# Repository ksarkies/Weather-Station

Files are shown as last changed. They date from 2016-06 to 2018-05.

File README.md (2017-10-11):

Weather Station
---------------

This project aims to produce a weather station consisting of a weatherproofed
processing unit for control and data capture from sensors. This would be
remotely mounted in a suitable location with the sensors and will communicate
with a base station over a serial cable or wirelessly.

The remote unit is ARM Cortex CM3 based and is powered either from the serial
link (if present) and/or from a solar panel with battery backup.

The base station collects and stores data and permit configuration of the
system via a user interface. It consists of a Linux based PC or microcomputer
unit.

Some of the sensors initially are taken from a defunct low cost commercial
weather station. Later they may be replaced with scientific grade sensors.

The sensors to be used are:

1. Temperature and humidity (indoor and outdoor),
2. Wind Speed,
3. Wind Direction,
4. Rainfall,
5. Barometric Pressure,
6. Solar Radiance.

The solar panel provided for power is also used to measure the incident
solar radiance. This is a measure specific to the panel type and is intended
only for providing records of incident radiance for use in design of solar
power generators having similar panel types.

**The battery must be present when the panel is connected**, as high voltages
from the panel can damage the components, and also because the panel is
disconnected from the power circuits during solar irradiance measurements,
which will result in the circuit losing all power.

(c) K. Sarkies 16/08/2017

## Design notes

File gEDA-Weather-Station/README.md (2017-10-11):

Weather Station Interface Board: gEDA Version
---------------------------------------------

This PCB version will not be updated. The Kicad version will be used instead.

This board provides the interface between the processor and the solar panel.
The panel is used to measure solar irradiation by measuring the (almost) short
circuit current which has a quite linear relationship with the incident
illuminance.

The panel is also used to charge the battery that powers the station. This
charging is done between measurements and is independent of them. A measurement
is taken by activating a digital output from the processor, which turns on a
MOSFET to the current measurement circuit. This effectively shorts out the
panel. At the same time the battery charger circuit is disabled to avoid any
possible interference with the measurements.

A small FM640A 6V 4AH Lead Acid battery is used for powering the system. 
The circuit manages battery charging by limiting the battery voltage through
a linear regulator with an output voltage controlled from the processor. The
battery voltage and charging current is passed to the processor for management
battery health.

A 3.3V power is supplied for the processor, and 5V power for the operational
amplifier. The LM324 has a 3.5V output limit with this supply voltage. The
LM324 also draws only about 0.7mA from the battery. The processor can be placed
into sleep mode between measurements to reduce power drain.

Design Notes
------------

The LM324 has been given a supply voltage VDD of 5V. The outputs can reach
VDD-1.5V which limits them to 3.5V; within the range of the processor input
voltage limits.

The variable voltage regulator based on the 7805 has a voltage setting 
resistor. The 7805 has a quiescent current of a few milliamps which flows
through this resistor and sets a minimum voltage. After some experimentation
it was found that a 470 ohm resistor would set a minimum voltage of 0.8V and a
maximum of 3.3V. The LM324 can source as much as 60mA which is sufficient to
maintain this maximum voltage. This provides an output voltage range between
5.5V and 8.0V. As long as it is more than 7.5V it will provide a valuable
natural limit on the battery charging voltage. Using a D/A converter to drive
this voltage will allow accurate setting of voltages according to battery
temperature. An option for testing purposes allows a fixed voltage provided by
jumper lead as any selected processor may not have a D/A converter. Once the
charging current falls below a given threshold the processor must terminate
charging.

A Schottky diode prevents the battery discharging back through the circuit when
measurements are being taken (as both MOSFETs may be on simultaneously for a
brief period when they are switched).

(c) K. Sarkies 10/06/2016

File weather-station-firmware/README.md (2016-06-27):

Weather Station Firmware
--------------------------

The firmware for the remote weather station unit provides interfacing to
the sensors in its vicinity. Communication with a base station or external PC
is done over a serial cable. It is possible that a wireless interface could be
added in the future.

The firmware powers down the unit to sleep, and wakes on interrupt from a
sensor, or at regular preset times to take measurements with non-interrupting
sensors and to make connection with any attached base station.

The firmware also controls charging of the backup battery from the solar
panel. This is done by monitoring the battery voltage during bulk charge and
applying a limit when it reaches absorption phase. Charging is then stopped
when the current falls below the 0.02C level (C being the battery capacity).

The Makefile currently includes the load script for the STM32F103RET6 used on
the ET Stamp module. Change this to STM32F103RBT6 if the ET-STM32F103
development board is used.

The sensors are allocated to the following GPIO ports:
* PA0 Rainfall Gauge using EXTI interrupt.
* PA1 Temperature and Humidity from DTH22.
* PA2 Wind speed using EXTI interrupt.
* PA3 Wind direction using EXTI interrupt.
* PA4 Solar radiance current using ADC12-IN4.
* Air pressure. This is I2C and needs I2C1_SCL on PB6 and I2C1_SDA on PB7.

For battery charging the following are needed:
* PA5 from a D/A converter DAC_OUT2 to control the battery charging voltage.
* PA6 to measure the battery voltage on ADC12-IN6.
* PA7 to measure the battery current on ADC12-IN7.
* PB4 to switch the panel to the solar radiance current measurement circuit.
* PB5 to disable battery charging.

This allocation allows ports to be used directly without remap on the STM32F103.

(c) K. Sarkies 07/05/2016

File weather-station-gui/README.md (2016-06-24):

Weather Station User Interface
------------------------------

This GUI is intended to run on an attached PC or base station. Its purpose
is to provide a display of current weather conditions, collect stored data and
allow control and configuration of the remote unit.

The GUI is taken substantially from the Battery Management System project with
reuse of the recording module to allow recorded data to be downloaded via the
serial interface. A configuration interface is also available.

(c) K. Sarkies 12/06/2016

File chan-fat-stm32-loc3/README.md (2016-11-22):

This is an adaptation of ChaN's FatFS FAT filesystem library based on v0.12.

Common files are ff.c, ff.h, ffconf.h, integer.h, diskio.h. These should be
updated when a new version of ChaN FAT library is released. Ensure that any
changes to ffconf.h are reflected in the new version.

The remaining files adapt the library to the hardware being used and to
libopencm3. Some changes to these may be necessary if the ChaN FAT API
changes.

Currently the makefile calls on sd_spi_loc3_stm32.c

(c) K. Sarkies 22/11/2016

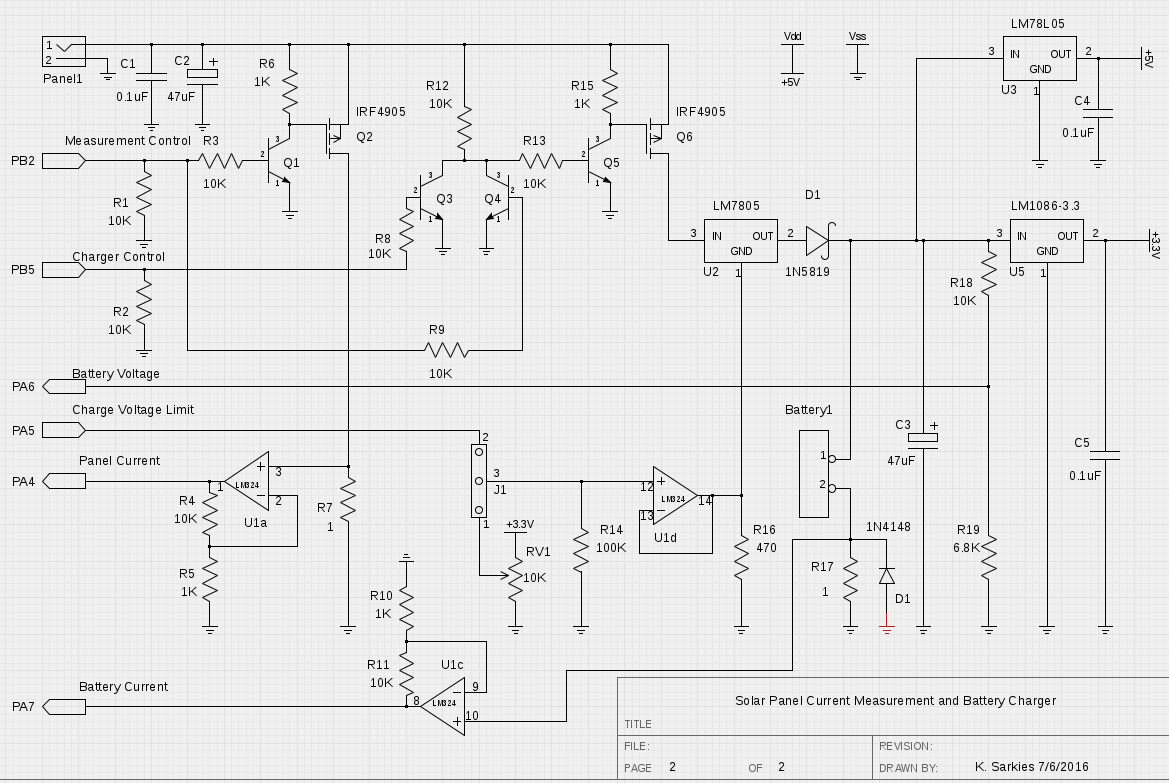
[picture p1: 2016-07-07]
gEDA-Weather-Station/weather-station-power.png

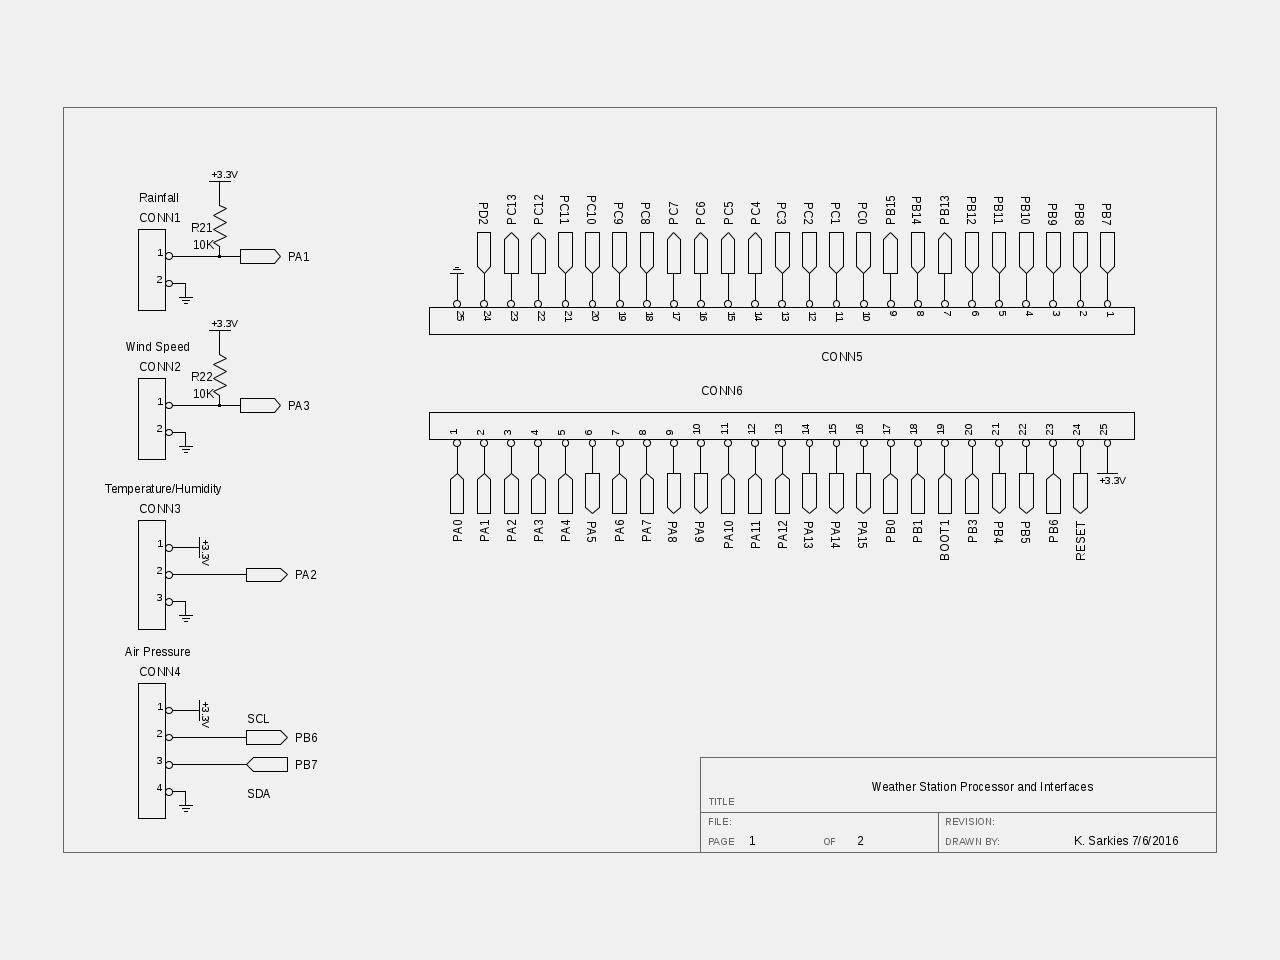
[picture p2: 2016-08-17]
gEDA-Weather-Station/weather-station-processor.png

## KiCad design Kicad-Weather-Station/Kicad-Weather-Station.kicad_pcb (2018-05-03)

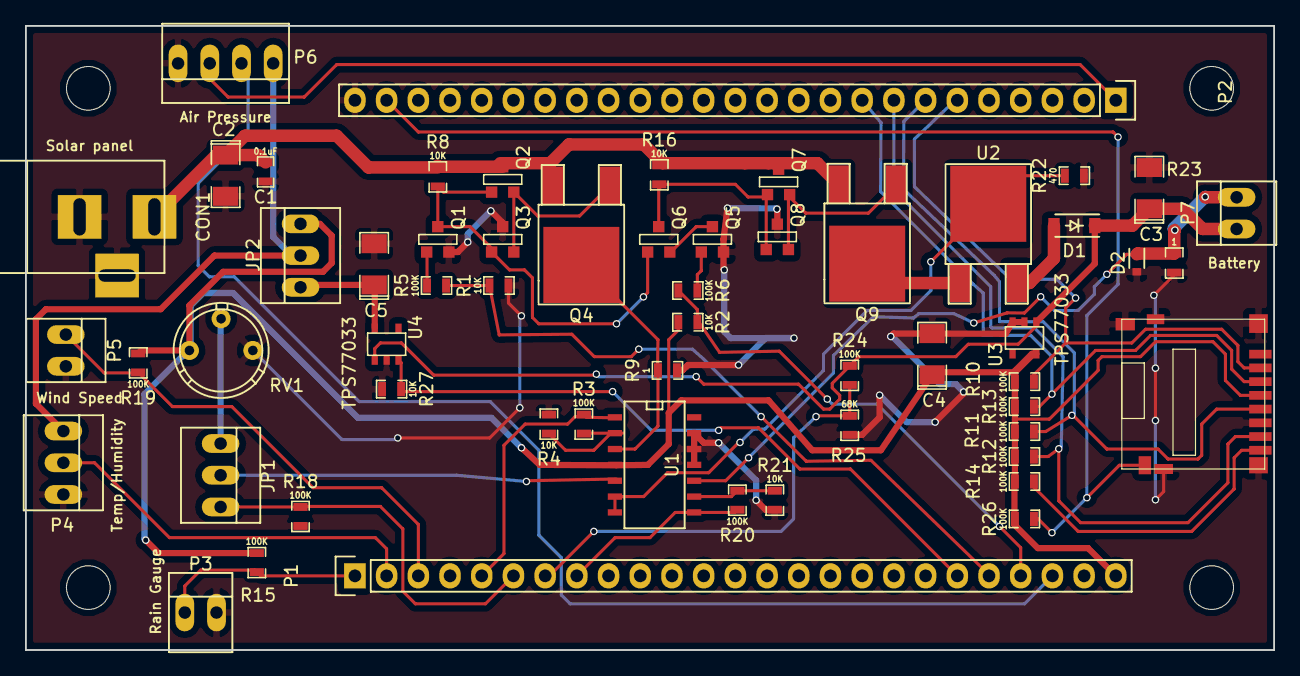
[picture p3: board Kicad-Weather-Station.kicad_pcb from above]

Board: 2 copper layers, 100.0 x 50.0 mm, 57 parts (0 on the bottom side), 40 nets.

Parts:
C1: 0.1uF; SM0603_Capa
C2, C3: 100uF; SM1206POL
C4, C5: 10uF; SM1206POL
CON1: Solar Panel; BARREL_JACK
D1: MBR0520LT1G; SOD-123
D2: 1N4148; SOD-523
J1: MicroSD; Conn_uSDcard_Amph_114_00841_68
JP1, JP2: JUMPER3; PINHEAD1-3
P1, P2: CONN_01X25; Pin_Header_Straight_1x25
P3: Rain Gauge; PINHEAD1-2
P4: Temperature/Humidity; PINHEAD1-3
P5: Wind Speed; PINHEAD1-2
P6: Air Pressure; PINHEAD1-4
P7: Battery; PINHEAD1-2
Q1, Q2, Q5, Q6, Q7: MMBT3904; SOT23EBC
Q3, Q8: MMBT3906; SOT23EBC
Q4, Q9: SUD45P03-12-GE3; TO-252-2Lead
R1, R2, R4, R8, R16, R21, R27: 10K; SM0603_Resistor
R3, R5, R6, R10, R11, R12, R13, R14, R15, R18, R19, R20, R24, R26: 100K; SM0603_Resistor
R9, R23: 1; SM0603_Resistor
R22: 470; SM0603_Resistor
R25: 68K; SM0603_Resistor
RV1: 100K; Potentiometer_Bourns_3339P_Angular_ScrewUp
U1: LMV324; SOIC-14_N
U2: 78M05; TO-252-2Lead
U3, U4: TPS77033; SOT23-5

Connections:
+3.3V: JP2.2, P4.1, P6.1
+3.3V-M: C4.1, J1.4, JP2.3, P1.25, R2.2, R10.1, R11.1, R12.1, R13.1, R14.1, R15.1, R19.2, R26.1, RV1.1, U1.4, U3.5
Earth: C1.2, C2.2, C3.2, C4.2, C5.2, CON1.2, CON1.3, D2.2, J1.6, J1.12, J1.SHLD, P2.25, P3.2, P4.3, P5.2, P6.4, Q1.1, Q3.3, Q5.1, Q8.3, R1.2, R4.2, R9.2, R18.2, R21.2, R22.2, R23.2, R25.2, R27.2, RV1.3, U1.11, U1.12, U1.13, U3.2, U3.3, U4.2
unnamed: C1.1, C2.1, CON1.1, Q2.3, Q4.3, Q7.3, Q9.3, R8.1, R16.1
unnamed: C5.1, JP2.1, U4.5
unnamed: D1.2, U2.3
unnamed: D2.1, P7.2, R23.1, U1.10
unnamed: JP1.1, RV1.2
unnamed: JP1.2, U1.5
unnamed: Q1.2, R5.1
unnamed: Q1.3, Q2.2, Q3.2, Q6.2, R8.2
unnamed: Q2.1, Q3.1, Q4.1
unnamed: Q4.2, R9.1, U1.3
unnamed: Q5.2, R6.1
unnamed: Q5.3, Q6.1
unnamed: Q6.3, Q7.2, Q8.2, R16.2
unnamed: Q7.1, Q8.1, Q9.1
unnamed: Q9.2, U2.1
unnamed: R3.2, R4.1, U1.2
unnamed: R20.2, R21.1, U1.9
unnamed: R22.1, U1.6, U1.7, U2.2
PA0: P1.1, P3.1, R15.2
PA1: P1.2, P4.2
PA2: P1.3, P5.1, R19.1
PA4: P1.5, R3.1, U1.1
PA5: JP1.3, P1.6, R18.1
PA6: P1.7, R24.2, R25.1
PA7: P1.8, R20.1, U1.8
PB3: P1.20, R27.1, U4.3
PB4: P1.21, R1.1, R5.2
PB5: P1.22, R2.1, R6.2
PB6: P1.23, P6.2
PB7: P2.1, P6.3
PB12: J1.2, P2.6, R10.2
PB13: J1.5, P2.7, R11.2
PB14: J1.7, P2.8, R12.2
PB15: J1.3, P2.9, R13.2
PD2: J1.11, P2.24, R26.2
Power: C3.1, D1.1, P7.1, R24.1, U3.1, U4.1
RSRVD: J1.8, R14.2

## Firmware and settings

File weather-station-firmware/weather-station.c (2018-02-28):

/**
@mainpage Weather Station Firmware for ARM based Remote Unit
@version 0.0.0
@author Ken Sarkies (www.jiggerjuice.info)
@date 04 July 2016

The program will place the processor into sleep mode for a given period of time
measured by the RTC alarm setting, which is the only clock still running in the
deep sleep (stop) mode. When expired, a scan of peripherals is made and the
results transmitted and recorded. During sleep, counting peripherals such as
rainfall and wind speed will temporarily wake the processor until the ISR is
complete and it will be placed back to sleep.

If the processor is placed into the lowest power stop mode, it cannot be
contacted by USART. In order to allow access by the base station, the processor
is first placed into sleep mode for a short time before being placed into stop
mode.

This initial development version uses the ET-ARM STAMP board. The port
allocations are:

- PA0: Rainwater gauge. Tipping bucket with reed switch.
- PA1: Temperature and Humidity. Freetronics DHT22.
- PA2: Wind Speed. Reed switch.
- PA3: Wind Direction. Reed switch.
- PA4: Solar Radiance (scale dependent on the panel material).
       Suntech-STP005S12-5W.
- Air Pressure. Freetronics MS-5637-02BA03. I2C-1 on PB6 for SCL, PB7 for SDA.

For battery charging the following are needed:
- PA6 to measure battery voltage on ADC12-IN5.
- PA7 to measure battery current on ADC12-IN6.
- PB2 to switch the panel to charge the battery.
- PB5 to switch the panel to the solar radiance current measurement circuit.

USART1 is on PA8-PA12 with Tx on PA9 and Rx on PA10.

For Memory card SPI interface:
- PD2: for memory card present signal.
- PB12: for memory card select.
- PB13: for memory card SCK.
- PB14: for memory card MISO.
- PB15: for memory card MOSI.

NOTE: The battery must be in place during operation otherwise when the charger
is disabled by the program the processor will power off.

NOTE: the test ET-STM32 STAMP board has a faulty PB4 and PB3.
*/

/*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
 * You should have received a copy of the GNU General Public License
 * along with this program.  If not, see <http://www.gnu.org/licenses/>.
 */

#include <stdint.h>
#include <stdbool.h>

#include <libopencm3/stm32/rtc.h>
#include <libopencm3/stm32/gpio.h>
#include <libopencm3/stm32/timer.h>
#include <libopencm3/stm32/usart.h>
#include <libopencm3/stm32/adc.h>
#include <libopencm3/stm32/dac.h>
#include <libopencm3/stm32/i2c.h>
#include <libopencm3/stm32/exti.h>
#include <libopencm3/cm3/systick.h>
#include <libopencm3/cm3/cortex.h>
#include <libopencm3/cm3/scb.h>
#include <libopencm3/cm3/nvic.h>
#include "../libs/buffer.h"
#include "../libs/comms.h"
#include "../libs/stringlib.h"
#include "../libs/file.h"
#include "../libs/timelib.h"
#include "../libs/dht.h"
#include "../libs/barosensor.h"
#include "../libs/i2clib.h"
#include "../libs/hardware.h"
#include "weather-station.h"
#include "weather-station-objdic.h"

/*--------------------------------------------------------------------------*/
/* Local Prototypes */

static void enable_radiance_measurement(void);
static void disable_radiance_measurement(void);
static void enable_charging(void);
static void disable_charging(void);
static uint8_t charger_active(void);
static void parse_command(uint8_t* line);

/*--------------------------------------------------------------------------*/
/* Global Variables */

static uint32_t rainfall;               /* Counter of interrupts from sensor */
static uint32_t wind_speed;             /* Counter of interrupts from sensor */
static uint8_t charger_is_active;       /* Existing state of charger */
static uint32_t measurement_period;
static uint8_t writeFileHandle;
static uint8_t readFileHandle;
static char writeFileName[12];
static char readFileName[12];
static bool deepSleep;                  /* Put processor into stop mode */
static bool lightSleep;                 /* Short term sleep mode in progress */
static bool scanNow;                    /* Request an immediate scan */
static uint32_t measurement_time;

/* These configuration variables are part of the Object Dictionary. */
/* This is defined in data-acquisition-objdic and is updated in response to
received messages. */
extern union ConfigGroup configData;

/*--------------------------------------------------------------------------*/

int main(void)
{
    set_global_defaults();
	hardware_init();
    DHT sensor_DHT = {DHT_PIN,DHT22,false};
    init_DHT(&sensor_DHT);
    init_comms_buffers();

    init_file_system();
    writeFileHandle = 0xFF;
    readFileHandle = 0xFF;
    writeFileName[0] = 0;
    readFileName[0] = 0;

    deepSleep = true;                   /* Start off in deep sleep */
    lightSleep = false;
    scanNow = true;

    charger_is_active = charger_active();
    uint8_t channel[1];                 /* Channel for A/D conversion */
    uint16_t charge_limit = 0;          /* voltage limit for charging battery */
    uint8_t i=0;
    comms_print_string("Weather Station\n\r");
    measurement_period = MEASUREMENT_PERIOD;
    measurement_time = rtc_get_counter_val() + measurement_period;
    uint32_t cnt;

    for (;;)
    {
/* -------- CLI ------------*/
/* Command Line Interface receiver interpretation.
 Process incoming commands as they appear on the serial input.
These will be fully processed before the processor goes to sleep mode.*/
        static uint8_t line[80];
        static uint8_t characterPosition = 0;
        if (receive_data_available())
        {
            uint8_t character = get_from_receive_buffer();
            if ((character == 0x0D) || (character == 0x0A) || (characterPosition > 78))
            {
                line[characterPosition] = 0;
                characterPosition = 0;
                parse_command(line);
            }
            else line[characterPosition++] = character;
        }
        if (! scanNow)
        {
/* Wait a bit for USART and any other outstanding operations to finish. */
            while (! usart_get_flag(USART1, USART_SR_TC)) {}
            for (cnt=0; cnt < 40000; cnt++) asm("nop");

/* Snooze for a while in low power stop mode. */
/* Possible power down modes are SLEEP or STOP modes only. These can be woken
by EXTI interrupts and so can register external events as well as RTC alarm for
periodical servicing of peripherals. If the USART is to be active during low
power mode then only SLEEP mode can be used. */

/* Just clear the whole bloody lot of exti pending requests */
            exti_reset_request(0xFFFFF);

/* -------- Deep Sleep ------------*/
/* The following would provide Deep Sleep (STOP) mode but at present this is
incompatible with USART usage. */
/* Use DEEPSLEEP mode if USART interrupts are not needed during sleep periods.
USART is powered off when the 1.8V regulator is powered down. */
#ifdef DEEPSLEEP
            if (deepSleep && ! lightSleep)
            {
/* Turn off peripherals during sleep (only ADC and DAC need to do this in STOP
mode if regulator low power is used). */
                peripheral_disable();
/* Don't set complete power down (otherwise it goes to standby and memory
contents are lost) */
                pwr_set_stop_mode();
/* Set deep sleep mode bit in SCB to go to stop mode */
                SCB_SCR |= SCB_SCR_SLEEPDEEP;
/* Set the 1.8V regulator to low power to preserve registers and SRAM but
power off core and digital peripherals. */
                pwr_voltage_regulator_low_power_in_stop();
            }
            else
#endif
            {
/* Clear power down bit */
                pwr_set_stop_mode();
/* Clear deep sleep mode bit in SCB in case it was previously set */
                SCB_SCR &= ~SCB_SCR_SLEEPDEEP;
/* Leave the 1.8V regulator on. */
                pwr_voltage_regulator_on_in_stop();
            }

            rtc_set_alarm_time(measurement_time);
            asm volatile("wfi");

/* Check if the wakeup source was the alarm. If so clear the alarm flag and
set the new alarm value ahead of the RTC. Signal a scan to take place. */
		    if (rtc_check_flag(RTC_ALR))
            {
                scanNow = true;
/* After light sleep mode period, go to main sleep period without scanning. */
                if (lightSleep)
                {
                    measurement_period = MEASUREMENT_PERIOD;
                    scanNow = false;
                    lightSleep = false;
                }
			    rtc_clear_flag(RTC_ALR);
                measurement_time = rtc_get_counter_val() + measurement_period;
            }

#ifdef DEEPSLEEP
/* Restore hardware clocks and any config that may have been lost. */
            if (deepSleep && ! lightSleep)
            {
                peripheral_enable();
                usart1_setup();
            }
#endif
        }

		if (scanNow)
        {
            scanNow = false;

/* Send out a time string */
            char timeString[20];
            put_time_to_string(timeString);
            send_string("pH",timeString);
            if (is_recording()) record_string("pH",timeString,writeFileHandle);

/* Send status message. Bit 0 represents deep sleep (stop) mode */
            uint8_t status = 0;
            if (deepSleep) status |= 0x01;
            send_response("ds",status);

/* These tasks are now performed whenever the RTC alarm wakes the processor.
Other interrupts will activate their ISR but are ignored and the processor
will go back into stop mode. */

/* Read and send Battery Voltage. */
            uint16_t voltage_raw = 0;
            channel[0] = ADC_CHANNEL6;          /* channel 6 battery voltage */
	        adc_set_regular_sequence(ADC1, 1, channel);
/* Average over 16 readings */
            for (i=0; i<16; i++)
            {
                adc_start_conversion_direct(ADC1);
                while (! adc_eoc(ADC1));
                voltage_raw += adc_read_regular(ADC1);
                delay(1);
            }
/* Voltage times 256 for fixed point scaling, with sense resistor (x10)
and amplification (x100) will give results in volts. */
            uint32_t voltage = ((voltage_raw>>4)*256*V_AMP)/(1241*100);/* Volts */
/* Read Battery Current. */
            uint32_t current_raw = 0;
            channel[0] = ADC_CHANNEL7;          /* channel 7 battery current */
	        adc_set_regular_sequence(ADC1, 1, channel);
/* Average over 16 readings */
            for (i=0; i<16; i++)
            {
                adc_start_conversion_direct(ADC1);
                while (! adc_eoc(ADC1));
                current_raw += adc_read_regular(ADC1);
            }
/* Current in mA times 256 for fixed point scaling, with sense resistor times 10
and current amplification and scale back to average 16 readings.
Note order of computations to avoid 32 bit overflow. */
            uint32_t current = 
                    ((current_raw*BATTERY_SENSE_RESISTOR*(1000/10))
                                /(1241*I_AMP_BATTERY))*(256/16);
            data_message_send("dB", current, voltage);
            if (is_recording()) record_dual("dB", current, voltage, writeFileHandle);
            delay(5);

/* Battery Charge Limit Setting */
            charge_limit = 4000;                 /* temporary for testing */
            dac_load_data_buffer_single(charge_limit, RIGHT12, CHANNEL_2);
            dac_software_trigger(CHANNEL_2);

/* Control Battery Charging.
This cycles between the absorption voltage limit and the float voltage limit. */
            if (voltage > CHARGE_LIMIT) {
                disable_charging();              /* Turn off battery charging */
            }
            if (voltage < FLOAT_LIMIT) {
                enable_charging();               /* Turn on battery charging */
            }

/* Offset for time that systick was asleep */
			millis_offset(measurement_period * 1000);
/* Read and send (Temperature and) Humidity from the DTH22. */
            uint32_t temperature;
            uint32_t humidity;
			bool error = ! read_temperature_humidity(&sensor_DHT, &temperature,
												   &humidity, false);
			if (! error)
            {
                send_response("dT", temperature);
                if (is_recording()) record_single("dT", temperature, writeFileHandle);
                send_response("dH", humidity);
                if (is_recording()) record_single("dH", humidity, writeFileHandle);
                delay(5);
            }

/* Read and send temperature and barometric pressure over i2c. */
            int32_t temp;
            int32_t pressure;
            error = ! get_baro_temp_and_pressure(&temp,&pressure,CELSIUS,OSR_4096);
			if (! error)
            {
//                comms_print_string("dT,");
//                comms_print_fixed_point(temp);
//                comms_print_string("\n\r");
                send_response("dP", pressure);
                if (is_recording()) record_single("dP", pressure, writeFileHandle);
                delay(5);
            }

/* Read and send solar panel current. Use simple polling of the ADC. */
            enable_radiance_measurement();
            int32_t radiance_raw = 0;
            channel[0] = ADC_CHANNEL4;          /* channel 4 radiance */
	        adc_set_regular_sequence(ADC1, 1, channel);
/* Average over 16 readings */
            for (i=0; i<16; i++) {
                adc_start_conversion_direct(ADC1);
                while (! adc_eoc(ADC1));
                radiance_raw += adc_read_regular(ADC1);
            }
            disable_radiance_measurement();       /* Puts charging back on */
/* Current in mA times 256 for fixed point scaling, with sense resistor times 10
and current amplification and scale back to average 16 readings.
Note order of computations to avoid 32 bit overflow. */
            uint32_t radiance =
                    ((radiance_raw*RADIANCE_SENSE_RESISTOR*(1000/10))
                                /(1241*I_AMP_RADIANCE))*(256/16);
            send_response("dL", radiance);
            if (is_recording()) record_single("dL", radiance, writeFileHandle);
            delay(5);

/* Send rain gauge count. */
            send_response("dR", rainfall);
            if (is_recording()) record_single("dR", rainfall, writeFileHandle);
            delay(5);
            cli();
            rainfall = 0;
            sei();

/* Send wind speed count. */
            send_response("dS", wind_speed);
            if (is_recording()) record_single("dS", wind_speed, writeFileHandle);
            delay(5);
            cli();
            wind_speed = 0;
            sei();

/* Set to a short light sleep period in case base station attempts to contact */
            lightSleep = true;
            measurement_time = rtc_get_counter_val() + LIGHT_SLEEP_TIME;
        }

/* Wait a bit for USART and any other outstanding operations to finish. */
        while (! usart_get_flag(USART1, USART_SR_TC)) {}
        for (cnt=0; cnt < 40000; cnt++) asm("nop");
	}

	return 0;
}

/*--------------------------------------------------------------------------*/
/* @brief Action a received USART command line.

*/

void parse_command(uint8_t* line)
{
/* ======================== Action commands ========================  */
/** Action Commands */
    if (line[0] == 'a')
    {
        switch (line[1])
        {
/* W Write the current configuration block to FLASH */
        case 'W':
            {
                write_config_block();
                break;
            }
/* Request identification string with version sent back.  */
        case 'E':
            {
                char ident[35] = "Weather Station,";
                string_append(ident,FIRMWARE_VERSION);
                send_string("dE",ident);
                break;
            }
/** Perform a scan. */
        case 'S':
            {
                if (! deepSleep) scanNow = true;
                break;
            }
        }
    }
/* ======================== Data request commands ================  */
/** Data Request Commands */
    else if (line[0] == 'd')
    {
        switch (line[1])
        {
/** Return the internal time. */
        case 'H':
            {
                char timeString[20];
                put_time_to_string(timeString);
                send_string("pH",timeString);
                break;
            }
        }
    }
/* ======================== Parameter commands ================  */
/**
Parameter Setting Commands */
    else if (line[0] == 'p')
    {
        switch (line[1])
        {
/* c-, c+ Turn communications sending on or off */
        case 'c':
            {
                if (line[2] == '-') configData.config.enableSend = false;
                else if (line[2] == '+') configData.config.enableSend = true;
                break;
            }
/* w-, w+ Turn deep sleep mode on or off (to allow USART communications) */
        case 'w':
            {
                if (line[2] == '-') deepSleep = false;
                else if (line[2] == '+') deepSleep = true;
                break;
            }
/* d-, d+ Turn on debug messages */
        case 'd':
            {
                if (line[2] == '+') configData.config.debugMessageSend = true;
                if (line[2] == '-') configData.config.debugMessageSend = false;
                break;
            }
/* Hxxxx Set time from an ISO 8601 formatted string. Echo back for GUI. */
        case 'H':
            {
                set_time_from_string((char*)line+2);
                char timeString[20];
                put_time_to_string(timeString);
                send_string("pH",timeString);
                measurement_time = rtc_get_counter_val() + measurement_period;
                break;
            }
/* M-, M+ Turn on/off data messaging (mainly for debug) */
        case 'M':
            {
                if (line[2] == '-') configData.config.measurementSend = false;
                else if (line[2] == '+') configData.config.measurementSend = true;
                break;
            }
/* r-, r+ Turn recording on or off */
        case 'r':
            {
                if (line[2] == '-') configData.config.recording = false;
                else if ((line[2] == '+') && (writeFileHandle < 0x0FF))
                    configData.config.recording = true;
                break;
            }
        }
    }

/* ======================== File commands ================ */
/*
F           - get free clusters
Wfilename   - Open file for read/write. Filename is 8.3 string style. Returns handle.
Rfilename   - Open file read only. Filename is 8.3 string style. Returns handle.
Xfilename   - Delete the file. Filename is 8.3 string style.
Cxx         - Close file. x is the file handle.
Gxx         - Read a record from read or write file.
Ddirname    - Get a directory listing. Directory name is 8.3 string style.
d[dirname]  - Get the first (if dirname present) or next entry in directory.
s           - Get status of open files and configData.config.recording flag
M           - Mount the SD card.
All commands return an error status byte at the end.
Only one file for writing and a second for reading is possible.
Data is not written to the file externally. */

/* File Commands */
    else if (line[0] == 'f')
    {
        switch (line[1])
        {
/* F Return number of free clusters followed by the cluster size in sectors. */
            case 'F':
            {
                uint32_t freeClusters = 0;
                uint32_t sectorsPerCluster = 0;
                uint8_t fileStatus = get_free_clusters(&freeClusters, &sectorsPerCluster);
                data_message_send("fF",freeClusters,sectorsPerCluster);
                send_response("fE",(uint8_t)fileStatus);
                break;
            }
/* d[d] Directory listing, d is the d=directory name. Get the first (if d
present) or next entry in the directory. If the name has a zero in the first
position, return the next entry in the directory listing. Returns the type,
size and name preceded by a comma. If there are no further entries found in the
directory, then size and name are not sent back. The type character can be:
 f = file, d = directory, n = error e = end */
            case 'd':
            {
                if (! file_system_usable()) break;
                char fileName[20];
                char type;
                uint32_t size;
                uint8_t fileStatus =
                    read_directory_entry((char*)line+2, &type, &size, fileName);
                char dirInfo[20];
                dirInfo[0] = type;
                dirInfo[1] = 0;
                if (type != 'e')
                {
                    char fileSize[5];
                    hex_to_ascii((size >> 16) & 0xFFFF,fileSize);
                    string_append(dirInfo,fileSize);
                    hex_to_ascii(size & 0xFFFF,fileSize);
                    string_append(dirInfo,fileSize);
                    string_append(dirInfo,fileName);
                }
                send_string("fd",dirInfo);
                send_response("fE",(uint8_t)fileStatus);
                break;
            }
/* Wf Open a file f=filename for writing less than 12 characters.
Parameter is a filename, 8 character plus dot plus 3 character extension.
Returns a file handle. On error, file handle is 0xFF. */
            case 'W':
            {
                if (! file_system_usable()) break;
                if (string_length((char*)line+2) < 12)
                {
                    uint8_t fileStatus =
                        open_write_file((char*)line+2, &writeFileHandle);
                    if (fileStatus == 0)
                    {
                        string_copy(writeFileName,(char*)line+2);
                        send_response("fW",writeFileHandle);
                    }
                    send_response("fE",(uint8_t)fileStatus);
                }
                break;
            }
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

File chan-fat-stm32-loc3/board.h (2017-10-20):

/* ChaN's FAT Disk I/O library.

MODIFIED FILE

Defines for the microcontroller board used.

The file is substantially that provided by Martin Thomas in his STM driver
contribution to the ChaN FAT library. It has been modified for libopencm3.

Only the two ET boards have been tested.

Check port settings against those set in the board.h header.
*/
/* Copyright (c) 2010, Martin Thomas, ChaN
   Copyright (c) 2013 Ken Sarkies
   All rights reserved.

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
  THIS SOFTWARE IS PROVIDED BY THE COPYRIGHT HOLDERS AND CONTRIBUTORS "AS IS"
  AND ANY EXPRESS OR IMPLIED WARRANTIES, INCLUDING, BUT NOT LIMITED TO, THE
  IMPLIED WARRANTIES OF MERCHANTABILITY AND FITNESS FOR A PARTICULAR PURPOSE
  ARE DISCLAIMED. IN NO EVENT SHALL THE COPYRIGHT OWNER OR CONTRIBUTORS BE
  LIABLE FOR ANY DIRECT, INDIRECT, INCIDENTAL, SPECIAL, EXEMPLARY, OR
  CONSEQUENTIAL DAMAGES (INCLUDING, BUT NOT LIMITED TO, PROCUREMENT OF
  SUBSTITUTE GOODS OR SERVICES; LOSS OF USE, DATA, OR PROFITS; OR BUSINESS
  INTERRUPTION) HOWEVER CAUSED AND ON ANY THEORY OF LIABILITY, WHETHER IN
  CONTRACT, STRICT LIABILITY, OR TORT (INCLUDING NEGLIGENCE OR OTHERWISE)
  ARISING IN ANY WAY OUT OF THE USE OF THIS SOFTWARE, EVEN IF ADVISED OF THE
  POSSIBILITY OF SUCH DAMAGE. */

#ifndef BOARD_H_
#define BOARD_H_

/* set to 1 to provide a disk_ioctrl function even if not needed by the FatFs */
#define STM32_SD_DISK_IOCTRL_FORCE      FALSE

#define STM32_SD_USE_DMA

/* The board being used is defined in the makefile */

#if defined USE_ET_STM32F103
/* GPIO C6 is WP, A8 is CP (not used), A4 is CS, A5 is SCK, A6 is MISO, A7 is MOSI, */
 #define CARD_SUPPLY_SWITCHABLE   FALSE
 #define SOCKET_WP_CONNECTED      TRUE  /* write-protect socket-switch */
 #define SOCKET_CP_CONNECTED      FALSE /* card-present socket-switch (clashes with USART1) */
 #define RCC_GPIO                 RCC_APB2ENR
 #define GPIO_PORT_WP             GPIOC
 #define RCC_GPIO_PORT_WP         RCC_APB2ENR_IOPCEN
 #define GPIOWP                   GPIO6
 #define GPIO_MODE_WP             GPIO_CNF_INPUT_FLOAT /* external resistor */
 #define GPIO_PORT_CP             GPIOA
 #define RCC_GPIO_PORT_CP         RCC_APB2ENR_IOPAEN
 #define GPIOCP                   GPIO8
 #define GPIO_MODE_CP             GPIO_CNF_INPUT_FLOAT /* external resistor */
 #define GPIO_PORT_CS             GPIOA
 #define RCC_GPIO_PORT_CS         RCC_APB2ENR_IOPAEN
 #define GPIOCS                   GPIO4
 #define SPI_SD                   SPI1
 #define DMA_CHANNEL_SPI_SD_RX    DMA_CHANNEL2
 #define DMA_CHANNEL_SPI_SD_TX    DMA_CHANNEL3
 #define DMA_FLAG_SPI_SD_TC_RX    DMA_TCIF
 #define DMA_FLAG_SPI_SD_TC_TX    DMA_TCIF
 #define GPIO_PORT_SPI_SD         GPIOA
 #define GPIOSPI_SD_SCK           GPIO5
 #define GPIOSPI_SD_MISO          GPIO6
 #define GPIOSPI_SD_MOSI          GPIO7
 #define RCC_SPI                  RCC_APB2ENR
 #define RCC_SPI_SD               RCC_APB2ENR_SPI1EN
/* - for SPI1 and full-speed APB2: 72MHz/4 */
 #define SPI_BaudRatePrescaler_fast    SPI_CR1_BR_FPCLK_DIV_4
 #define SPI_BaudRatePrescaler_slow    SPI_CR1_BR_FPCLK_DIV_256

#elif defined USE_ET_STAMP_STM32
/* GPIO WP not used, D2 is CP, B12 is CS, B13 is SCK, B14 is MISO, B15 is MOSI */
 #define CARD_SUPPLY_SWITCHABLE   FALSE
 #define SOCKET_WP_CONNECTED      FALSE /* write-protect socket-switch */
 #define SOCKET_CP_CONNECTED      FALSE /* card-present socket-switch */
 #define RCC_GPIO                 RCC_APB2ENR
// #define GPIO_PORT_WP             GPIOB
// #define RCC_GPIO_PORT_WP         RCC_APB2ENR_IOPBEN
// #define GPIOWP                   GPIO11
// #define GPIO_MODE_WP             GPIO_CNF_INPUT_FLOAT /* external resistor */
 #define GPIO_PORT_CP             GPIOD
 #define RCC_GPIO_PORT_CP         RCC_APB2ENR_IOPDEN
 #define GPIOCP                   GPIO2
 #define GPIO_MODE_CP             GPIO_CNF_INPUT_FLOAT /* external resistor */
 #define GPIO_PORT_CS             GPIOB
 #define RCC_GPIO_PORT_CS         RCC_APB2ENR_IOPBEN
 #define GPIOCS                   GPIO12
 #define SPI_SD                   SPI2
 #define DMA_CHANNEL_SPI_SD_RX    DMA_CHANNEL4
 #define DMA_CHANNEL_SPI_SD_TX    DMA_CHANNEL5
 #define DMA_FLAG_SPI_SD_TC_RX    DMA_TCIF
 #define DMA_FLAG_SPI_SD_TC_TX    DMA_TCIF
 #define GPIO_PORT_SPI_SD         GPIOB
 #define GPIOSPI_SD_SCK           GPIO13
 #define GPIOSPI_SD_MISO          GPIO14
 #define GPIOSPI_SD_MOSI          GPIO15
 #define RCC_SPI                  RCC_APB1ENR
 #define RCC_SPI_SD               RCC_APB1ENR_SPI2EN

/* - for SPI2 and full-speed APB1: 36MHz/2 */
 #define SPI_BaudRatePrescaler_fast    SPI_CR1_BR_FPCLK_DIV_4
 #define SPI_BaudRatePrescaler_slow    SPI_CR1_BR_FPCLK_DIV_256
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

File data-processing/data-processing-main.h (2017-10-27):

/**
@mainpage Data Processing Main Window
@version 1.0
@author Ken Sarkies (www.jiggerjuice.net)
@date 08 August 2017
*/

/****************************************************************************
 *   Copyright (C) 2017 by Ken Sarkies                                      *
 *   ksarkies@internode.on.net                                              *
 *                                                                          *
 *   This program is free software; you can redistribute it and/or          *
 *   modify it under the terms of the GNU General Public License as         *
 *   published by the Free Software Foundation; either version 2 of the     *
 *   License, or (at your option) any later version.                        *
 *                                                                          *
 *   This program is distributed in the hope that it will be useful,        *
 *   but WITHOUT ANY WARRANTY; without even the implied warranty of         *
 *   MERCHANTABILITY or FITNESS FOR A PARTICULAR PURPOSE.  See the          *
 *   GNU General Public License for more details.                           *
 *                                                                          *
 *   You should have received a copy of the GNU General Public License      *
 *   along with this program if not, write to the                           *
 *   Free Software Foundation, Inc.,                                        *
 *   51 Franklin St, Fifth Floor, Boston, MA  02110-1301  USA.              *
 ***************************************************************************/

#ifndef DATA_PROCESSING_MAIN_H
#define DATA_PROCESSING_MAIN_H

// Parameters of the voltage and current amplifiers
#define R9 20
#define R7 10
#define R4 10
#define R5 2.2
#define Vref 2.5
#define Ioffset 3.3/2
#define Iscale 10

#define Voffset R9*Vref/R5
#define Vscale (1+R4/R5)/(1+R9/R7)

#define LINE_WIDTH 16

#include "ui_data-processing-main.h"
#include <QDialog>
#include <QDir>
#include <QFile>
#include <QFileInfo>

typedef enum {battery1UnderVoltage, battery2UnderVoltage, battery3UnderVoltage, 
              battery1OverCurrent, battery2OverCurrent, battery3OverCurrent,
              load1UnderVoltage, load2UnderVoltage, panelUnderVoltage, 
              load1OverCurrent, load2OverCurrent, panelOverCurrent, }
              IndicatorType;

#define millisleep(a) usleep(a*1000)

/* Maximum current put out by the solar panel */
#define MAX_SOLAR_CURRENT 330

//-----------------------------------------------------------------------------
/** @brief Power Management Main Window.

*/

class DataProcessingGui : public QMainWindow
{
    Q_OBJECT
public:
    DataProcessingGui();
    ~DataProcessingGui();
    bool success();
private slots:
    void on_openReadFileButton_clicked();
    void on_dumpAllButton_clicked();
    void on_analysisFileSelectButton_clicked();
private:
// User Interface object instance
    Ui::DataProcessingMainWindow DataProcessingMainUi;
    void scanFile(QFile* file);
    bool combineRecords(QDateTime startTime, QDateTime endTime,
                                   QFile* inFile, QFile* outFile, bool header);
    void displayErrorMessage(QString message);
    QDateTime findFirstTimeRecord(QFile* inFile);
    bool openSaveFile(void);
    bool outfileMessage(QString filename, bool* append);
    QStringList recordType;
    QStringList recordText;
    QFile* inFile;
    QFile* outFile;
    QString saveFile;
    QDir saveDirectory;
    QFileInfo fileInfo;
// Record information
    QString timeRecord;
};

#endif

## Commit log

2016-05-10 Add DHT sensor library from Adafruit Industries, generalised. Not complete or tested.
2016-05-19 Recast DHT.c as C code using a datastructure for the DHT object. hardware.c holds replacement code for the Arduino calls originally used. The low level read/write in DHT.c was changed to generalise t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
    [weather-station.c]
2016-05-20 Change from floating point to fixed point arithmetic. Addition of timer and USART functions and flesh out the main test program. Still untested.
    [weather-station.c]
2016-05-23 Fixed some bugs that caused the delay loops to hang. Rearrange to place all hardware oriented features into hardware.c along with some utility functions for printout.
    [weather-station.c]
2016-05-24 Change timing to set systick to a longer timeout period and compute milliseconds from the systick settings and register values. Add a delaySleep function to sleep until systick timeout interrupt.
2016-06-06 Minor mods to the firmware to get a working test for humidity/temperature.
2016-06-06 First start at mods to barometric sensor code forked from Freetronics. Aim to convert to C code as with the humidity sensor code.
2016-06-06 Schematic for interface board to handle the battery charging and solar panel current measurement. This uses a simple linear regulator plus a D/A output from the processor to limit the battery voltage.
    [weather-station.sch]
2016-06-07 Update to interface circuit to add battery current measurement.
    [weather-station.sch]
2016-06-09 Some component changes following testing.
    [weather-station.sch]
2016-06-12 Add a basic GUI with T and H. Modify firmware to match requirements for CSV communications. Wind direction is omitted until a compass widget can be installed (and a sensor obtained).
2016-06-23 Updates to the firmware to implement A/D conversions and D/A conversion. Some rearrangement of hardware initialization between main file and lib file. Start on i2c needing more work. Not yet imopleme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
2016-06-23 Addition of circuit diagram.
    [weather-station-power.sch, weather-station-processor.sch, weather-station.sch]
2016-06-24 Complete the EXTI portion. DAC attempted but not working yet. Had to go to ET-STAMP as the ET-STM32F103 dev board failed to activate EXTI if the ADC or Timer2 (sharing pins) were activated. Probably 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
    [weather-station.c]
2016-06-27 Add battery charging feature. All A/D conversions now averaged over 16 reads.
2016-07-04 More updates to firmware. Change PB4 to PB3 for radiance measurement as the port PB4 on the board benig used is dead.
2016-07-04 Modifications to i2c and further work on barometric sensor code.
2016-07-05 Fix some problems with measurement of currents andmove irradiance switch to PB2 due to faulty hardware.
    [weather-station-power.sch]
2016-07-07 Minor updates to the schematics.
    [weather-station-power.sch, weather-station-processor.sch]
2016-07-14 Completion of rtc-test using stop mode, interrupts, RTC alarm wakeup and other EXTI interrupts.
2016-07-15 Prettify GUI and add battery health display
2016-07-15 Firmware update to put processor to stop mode using RTC alarm. Add air pressure (sending dummy for now)
2016-07-16 Fix problem with T and H reading due to systick stopping during sleep. The sensor requires 2 seconds minimum between reads. As systick was stopped, the program thought that not enough time had elapse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
    [weather-station.c]
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2016-07-24 First hack at Kicad board for manufacture. Schematic not finished.
    [Kicad-Weather-Station.kicad_pcb, Kicad-Weather-Station.sch]
2016-07-25 Update to schematics. Kicad version completed with values and annotation.
    [Kicad-Weather-Station.sch, weather-station-power.sch]
2016-07-25 Add footprints and create PCB. Some layout started. Trimpot footprint to be defined.
    [Kicad-Weather-Station.kicad_pcb, Kicad-Weather-Station.sch]
2016-07-26 Initial layout of PCB
    [Kicad-Weather-Station.kicad_pcb]
2016-07-26 Oops! forgot the microSD card. Rearrangement of PCB layout to accommodate.
    [Kicad-Weather-Station.kicad_pcb, Kicad-Weather-Station.sch]
2016-07-27 First form of PCB
    [Kicad-Weather-Station.kicad_pcb, Kicad-Weather-Station.sch]
2016-07-31 Generate Gerbers and images
    [Kicad-Weather-Station-B.Cu.gbr, Kicad-Weather-Station-B.Mask.gbr, Kicad-Weather-Station-B.SilkS.gbr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]
2016-08-17 Update firmware to start integration of barometric pressure sensor and USART read. For the latter change from deep sleep to light sleep so that the USART interrupt can be recognised.
2016-08-17 Add image of processor portion of prototype circuit and remove PCB.
2016-08-22 Add barometric sensor feature. Based on I2C. Returns T with better accuracy than the humidity sensor. Update GUI to prettify and add a recording header. An odd problem exists in that the constants ob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
    [weather-station.c]
2016-08-27 Add Amphenol microSD connector to PCB.
    [Kicad-Weather-Station.kicad_pcb, Kicad-Weather-Station.sch]
2016-08-27 Add Amphenol microSD connector to PCB and add the CP (card present) signal to PA8.
    [Kicad-Weather-Station-B.Cu.gbr, Kicad-Weather-Station-B.Mask.gbr, Kicad-Weather-Station-B.SilkS.gbr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]
2016-11-22 Update to PCB and gerbers
    [Kicad-Weather-Station-B.Cu.gbr, Kicad-Weather-Station-B.Mask.gbr, Kicad-Weather-Station-B.SilkS.gbr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]
2016-11-22 Fix deprecated ADC calibration sequence
2017-10-12 Further changes to firmware to use common set of functions with underline name format. Correction of error in I2C library. Removal of comms functions from the hardware library. Separation of string f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
    [weather-station.c]
2017-10-20 Get file recording in firmware to work by moving various functions closer to those used in the data acquisition project. chan_fat is now identical as are the libraries except for hardware.c. The comp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
    [board.h, diskio.h, sd_spi_loc3_stm32.c]
2017-10-21 Repair code to print fixed point and place in string lib. Add fixed point record to file Combine battery voltage and current to one message as in other projects. Send a time string each message block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
    [weather-station.c]
2017-10-21 Add a sensor enable circuit to allow switching of power to sensors that are used only when the processor is awake, to save energy.
    [Kicad-Weather-Station.sch]
2017-10-21 Add configure window same as for Data Acquisition. Had to remove reference to RTC in firmware as it was being used for setting and retrieving real time. This must be done through the systick timer as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
2017-10-26 Change to circuit to allow certain peripherals to be powered off during sleep when not required. Peripherals that perform counting are not powered off.
    [Kicad-Weather-Station.sch]
2017-10-26 Minor change to colours of buttons in GUI.
2017-10-26 Add data processing mainly intended at this stage to convert combine records and convert to csv form.
2017-10-27 Change transmission format in firmware to send fixed point as integer (times 256) rather than as floating number. Change GUI and data processing to match.
    [data-processing-main.h, weather-station.c, weather-station.h]
2017-10-30 Fix problem with measurement cycle at change of time setting. Add change to deep sleep through button press. NOTE: the change back to sleep mode has not yet been achieved apart from a hardware reset.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
    [weather-station.c, weather-station.h]
2017-11-03 Fix problem where DAC setting affected pA0 and PA3 rather than PA5
    [weather-station.c]
2017-11-14 Corrections to PCB schematic.
    [Kicad-Weather-Station.sch]
2017-12-25 Update schematic and PCB to allow some sensors to be powered off.
    [Kicad-Weather-Station.kicad_pcb, Kicad-Weather-Station.sch]
2018-01-18 Clean up PCB footprints and generate gerbers.
    [Kicad-Weather-Station-B.Cu.gbr, Kicad-Weather-Station-F.Cu.gbr, Kicad-Weather-Station.drl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]
2018-01-19 Regenerate gerbers
    [Kicad-Weather-Station.drl, Kicad-Weather-Station.gbl, Kicad-Weather-Station.gbo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]
2018-02-28 Fix firmware source to refer to the header file. Remove tabs from makefile
    [weather-station.c]
2018-05-02 Added missing inversion stage for battery charge MOSFET driver section. Removed clunky earth pin holes and added tracks with vias in the earthing part to ensure that all earths can be connected after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
    [Kicad-Weather-Station.kicad_pcb, Kicad-Weather-Station.sch]
2018-05-03 Second version of changes to fix MOSFET drivers. Use AND gate form of inverter to ensure that battery charge MOSFET is off when solar panel measurement is on. This does not need any transistors and i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
    [Kicad-Weather-Station.kicad_pcb, Kicad-Weather-Station.sch]

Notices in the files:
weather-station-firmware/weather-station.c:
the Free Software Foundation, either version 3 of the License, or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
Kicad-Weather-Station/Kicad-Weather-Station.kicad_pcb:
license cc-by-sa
